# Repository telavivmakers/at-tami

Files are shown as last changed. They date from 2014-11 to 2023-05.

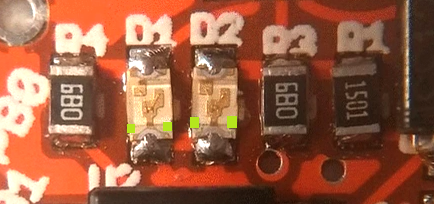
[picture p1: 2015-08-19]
assembly/led_attami.png

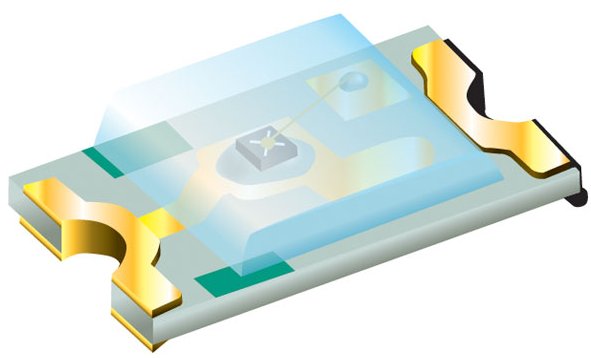
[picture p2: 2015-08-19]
assembly/0805led.jpg

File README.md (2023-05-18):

ATtami עָלֵקדוּאִינו
=================

fork of littlewire AVR based Vusb dev board and various other efforts around the ATtiny85 <br>
more at [docs.telavivmakers.space/attami](https://docs.telavivmakers.space/attami)<br>

Schematics
===

[ATtami board schema](https://github.com/telavivmakers/at-tami/raw/master/ATTAMI-V0.00.sch.pdf)

board layout
===

ATtami board (ver 2.1) backside
ATtami board (ver 2.1)

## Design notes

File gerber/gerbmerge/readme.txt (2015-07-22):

== ATtami-ver-17 8/19/2014 ==
gerber files for 4x4 panel (10x10cm)

panel processed using gerbv[1] python script
from CAM job made via eagle PCB[2]
includes .gvp file which is a gerber viewer[3]

contact yair99@gmail.com

[1] http://174.136.57.11/~ruggedci/gerbmerge/
[2] http://www.cadsoftusa.com/
[3] http://gerbv.sourceforge.net/

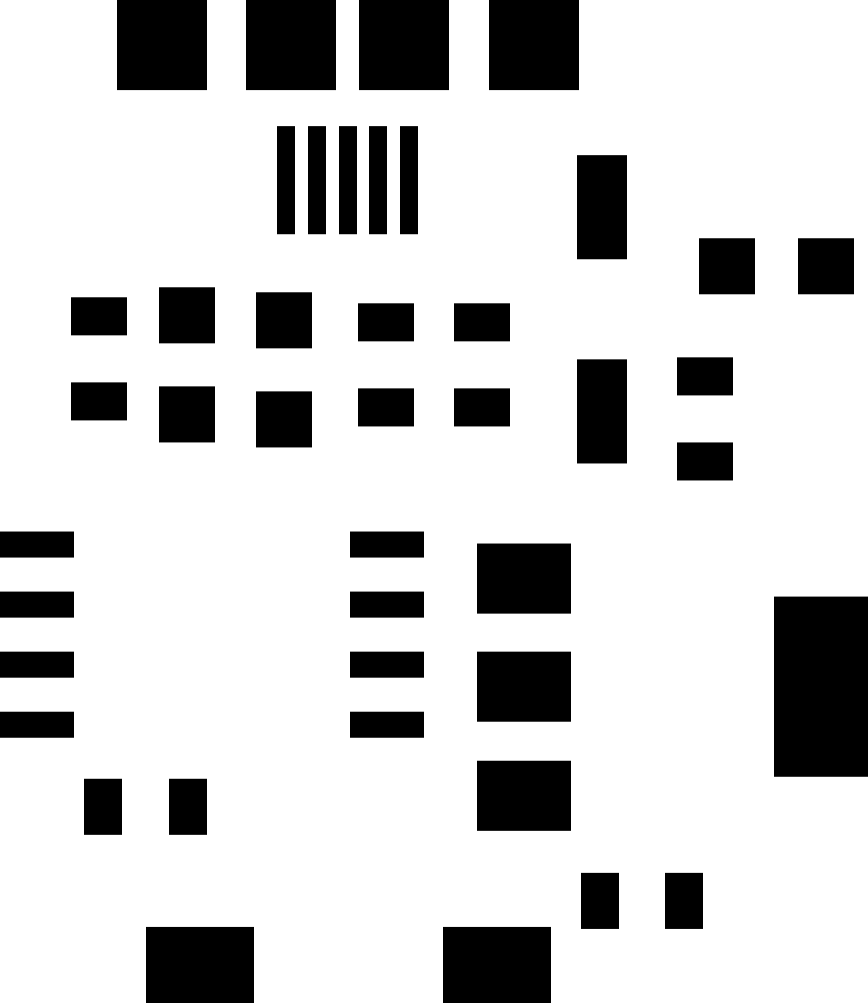
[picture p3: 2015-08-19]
plotter/ATtami-V00-stencil-elragex4.png

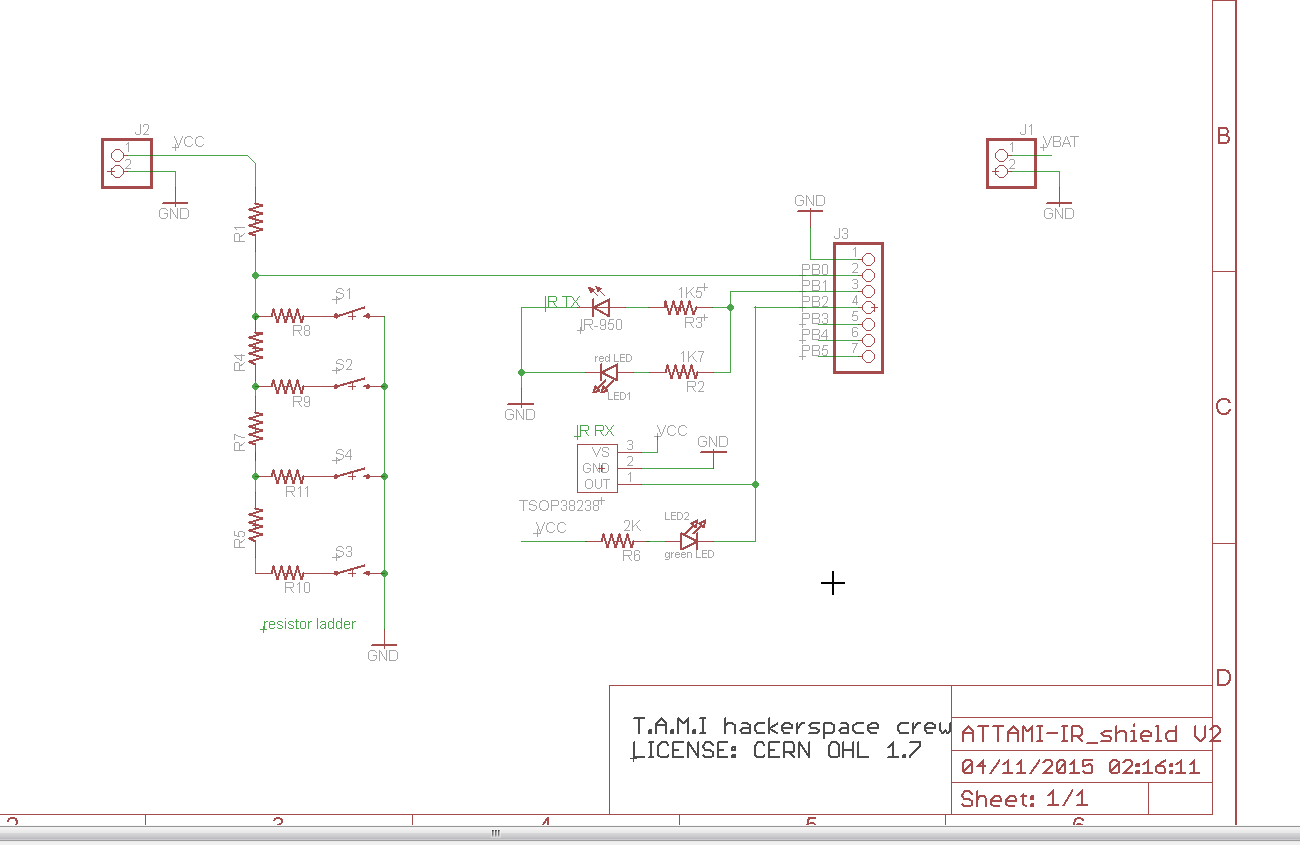
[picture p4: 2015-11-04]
shields/ir-shield/ir-sheild.png

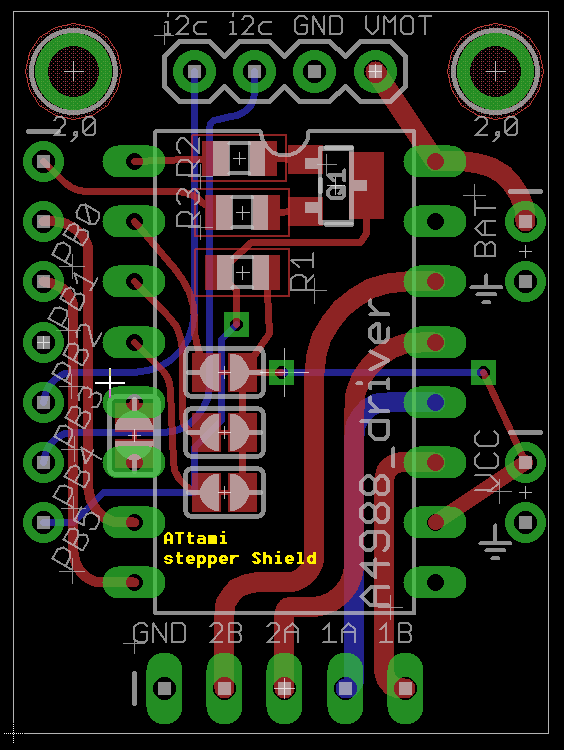
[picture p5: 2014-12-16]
shields/stepperDriver/ATTAMI-Shield-stepperDriver.brd.png

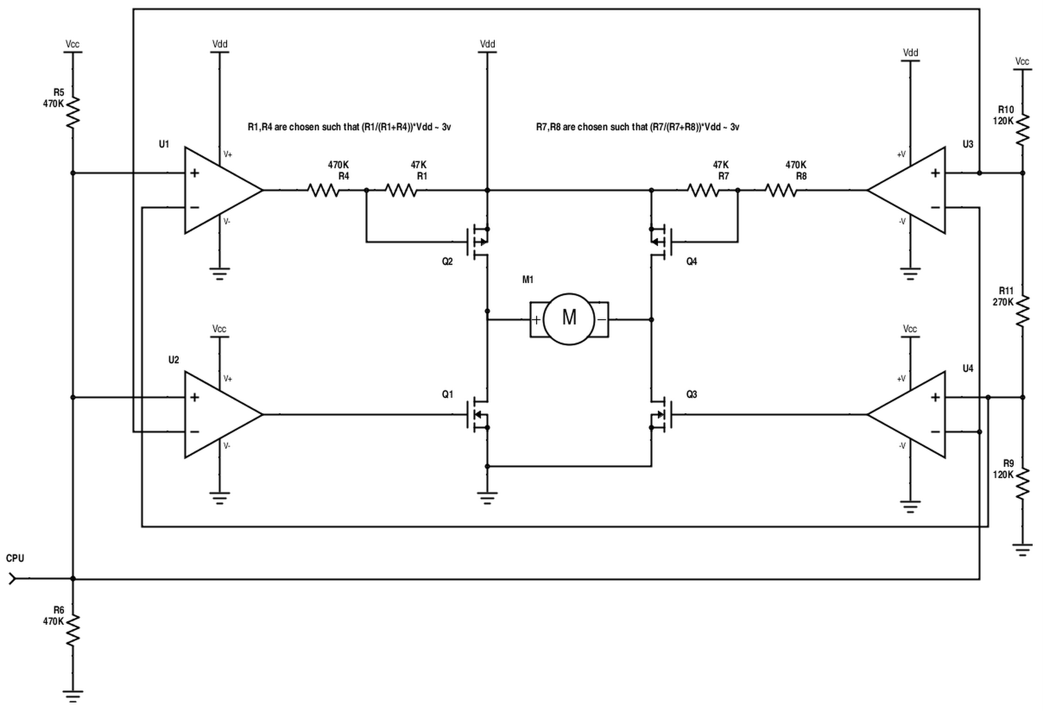
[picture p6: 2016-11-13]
shields/diyStepperDriver/udi_hbridge_w_opamps.png

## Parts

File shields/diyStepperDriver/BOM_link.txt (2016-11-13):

https://docs.google.com/spreadsheets/d/1dIvlz9Zhw2C25BC9nijCdQvVHDtH89HcU7y3oBZd_WM/edit#gid=0

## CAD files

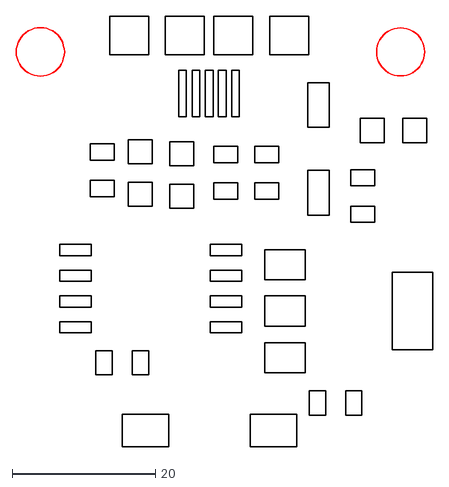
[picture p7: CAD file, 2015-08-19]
plotter/ATtami-V00-stencil.dxf
58.1 x 60.1

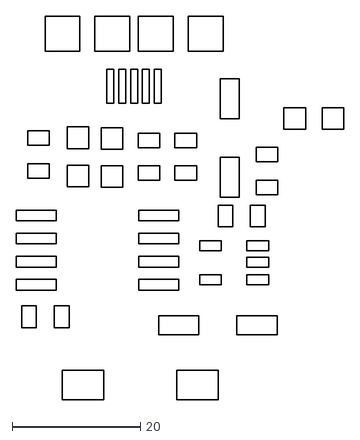
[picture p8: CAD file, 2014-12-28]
plotter/drawing.dxf.DesktopCuttingPlotter.dxf
51.0 x 59.7

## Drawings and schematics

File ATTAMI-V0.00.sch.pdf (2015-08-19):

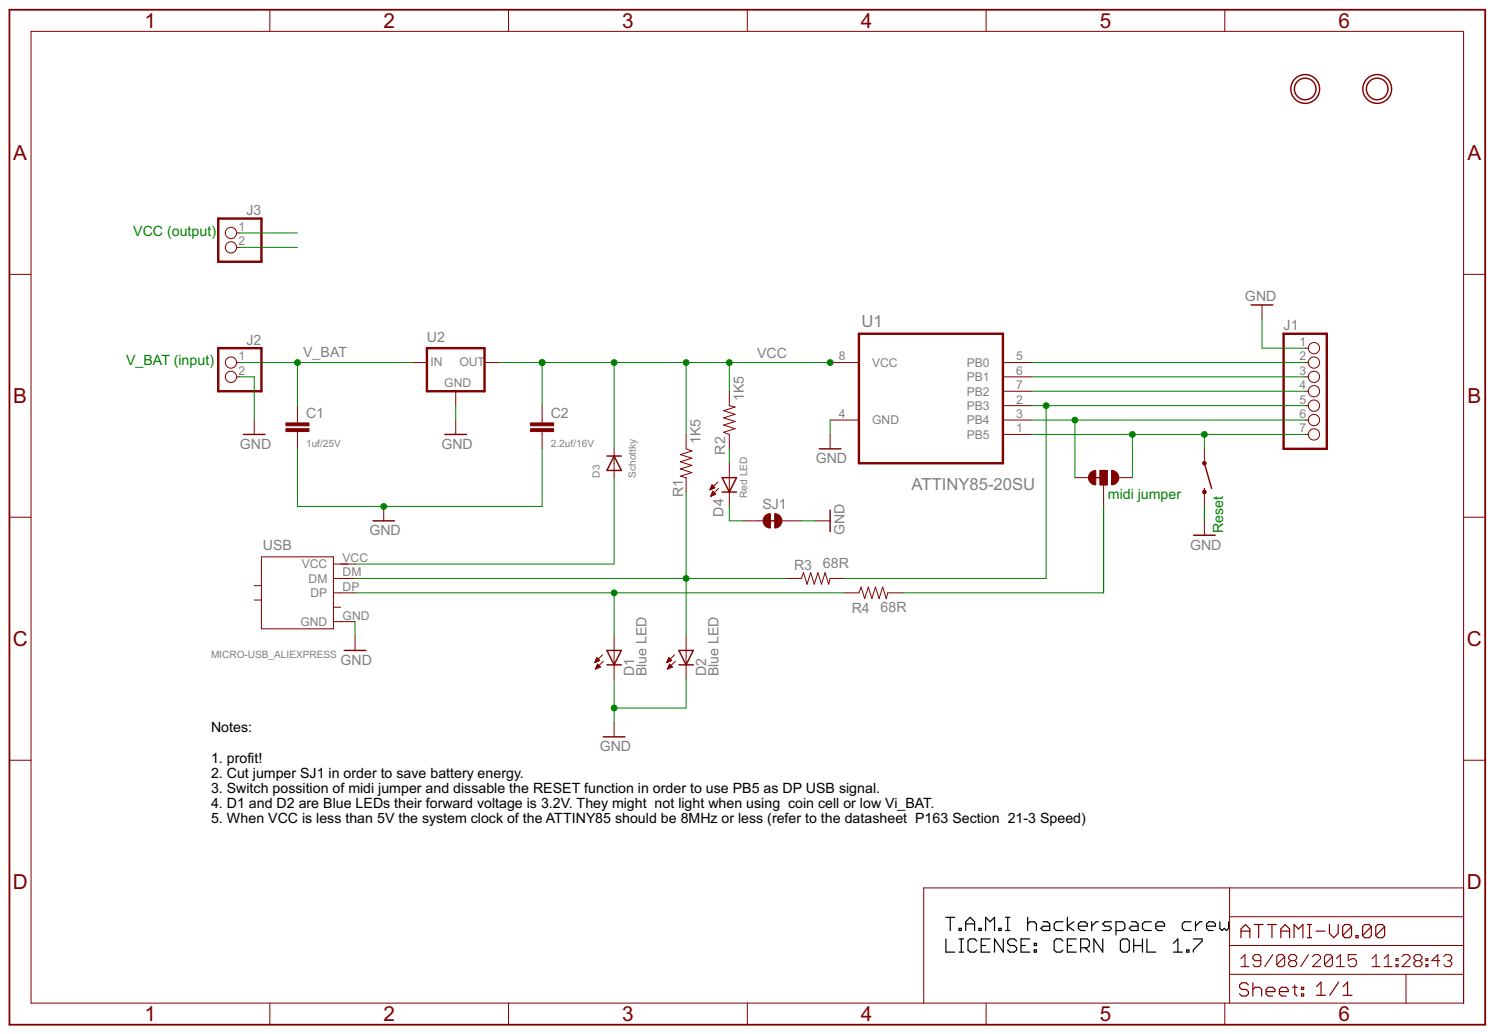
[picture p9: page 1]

2. Cut jumper SJ1 in order to save battery energy. 3. Switch possition of midi jumper and dissable the RESET function in order to use PB5 as DP USB signal. 4. D1 and D2 are Blue LEDs their forward voltage is 3.2V. They might not light when using coin cell or low Vi_BAT. 5. When VCC is less than 5V the system clock of the ATTINY85 should be 8MHz or less (refer to the datasheet P163 Section 21-3 Speed)

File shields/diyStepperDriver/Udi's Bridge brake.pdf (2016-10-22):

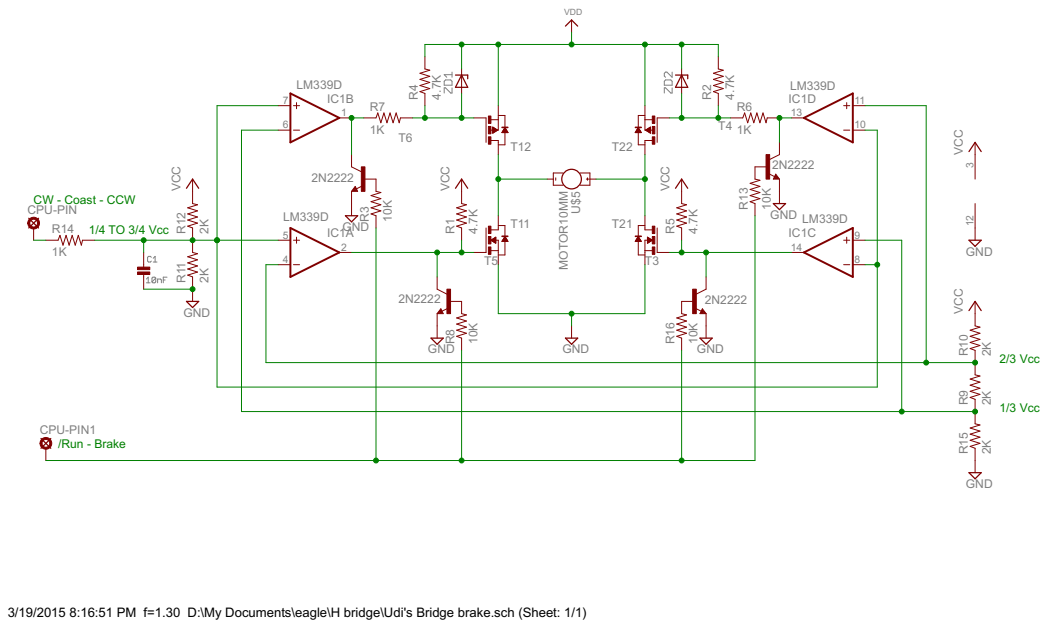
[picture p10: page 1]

3/19/2015 8:16:51 PM f=1.30 D:\My Documents\eagle\H bridge\Udi's Bridge brake.sch (Sheet: 1/1)

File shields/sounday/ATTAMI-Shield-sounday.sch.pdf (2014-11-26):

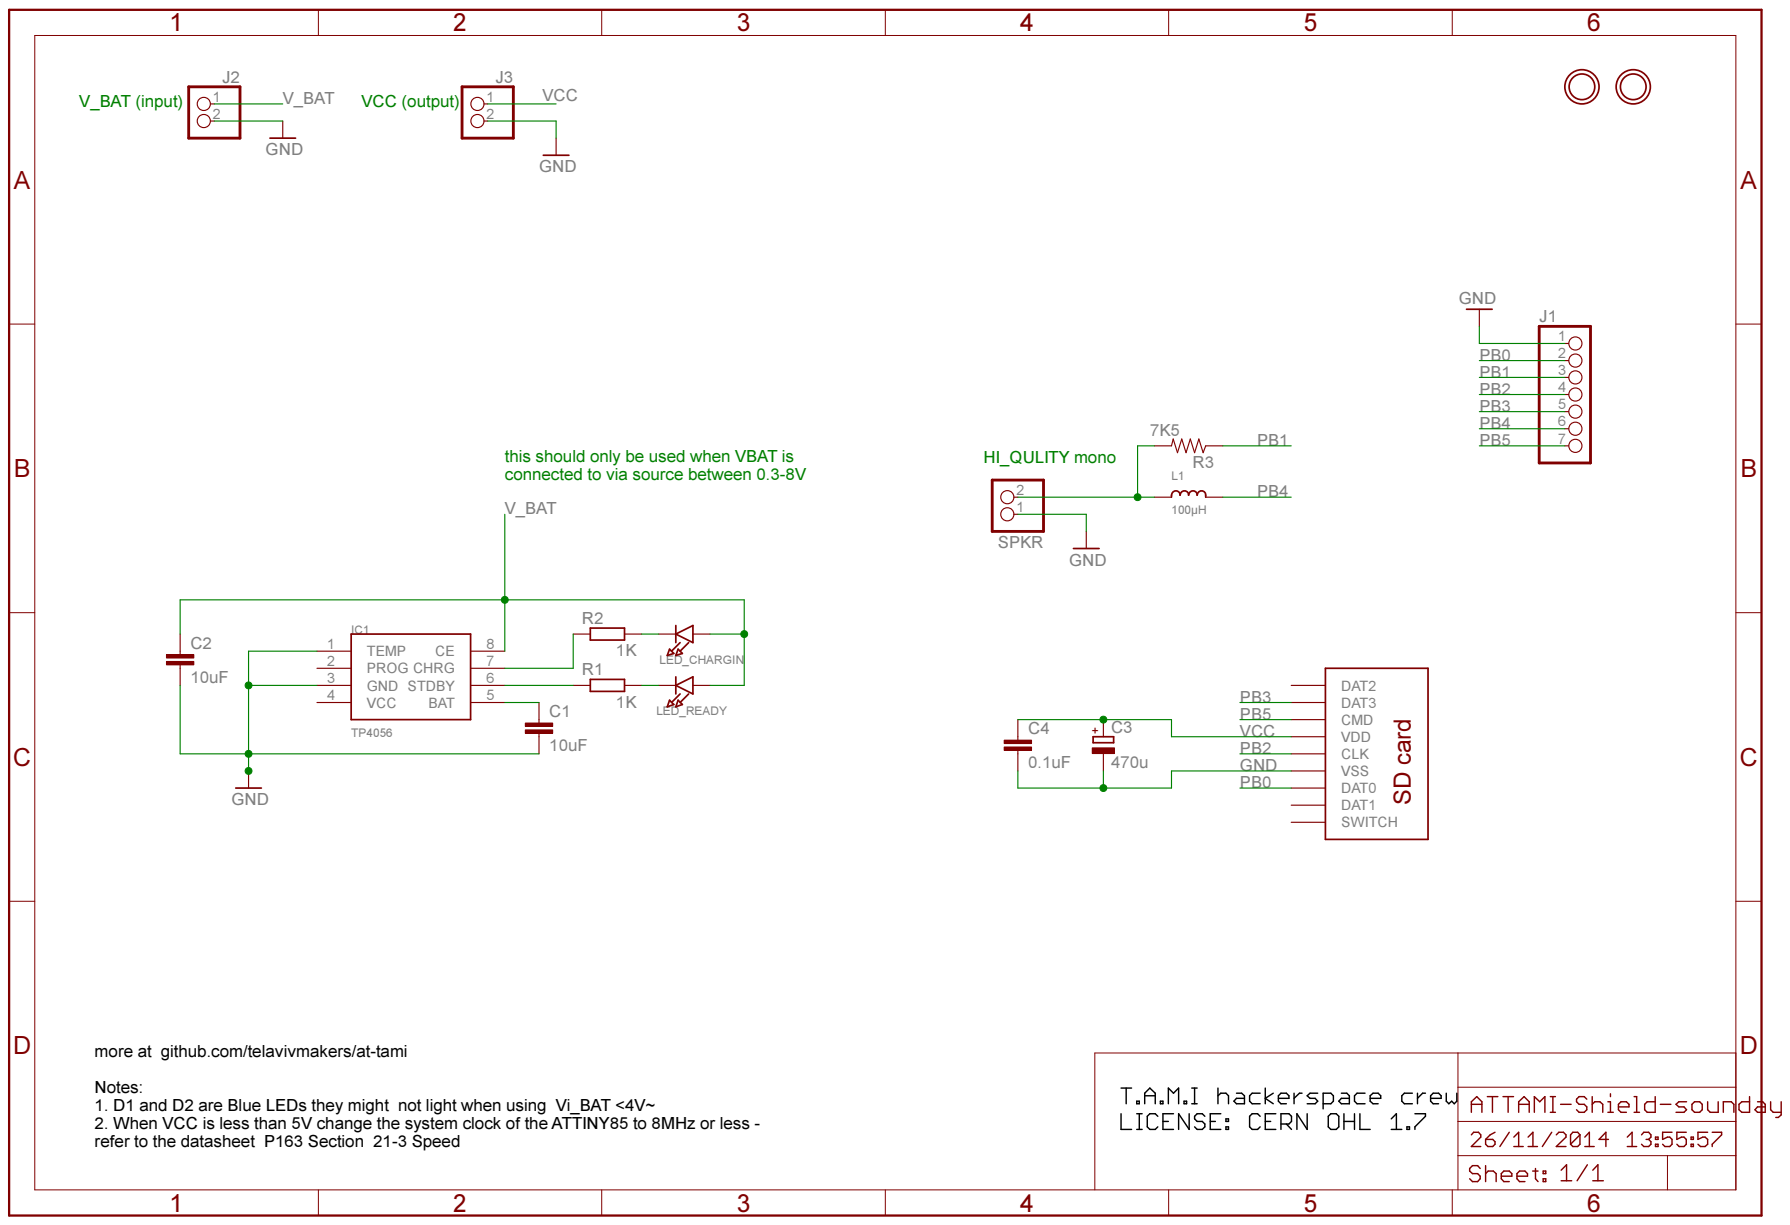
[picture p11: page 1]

this should only be used when VBAT is
connected to via source between 0.3-8V

more at github.com/telavivmakers/at-tami

Notes:
1. D1 and D2 are Blue LEDs they might not light when using Vi_BAT <4V~
2. When VCC is less than 5V change the system clock of the ATTINY85 to 8MHz or less -
refer to the datasheet P163 Section 21-3 Speed

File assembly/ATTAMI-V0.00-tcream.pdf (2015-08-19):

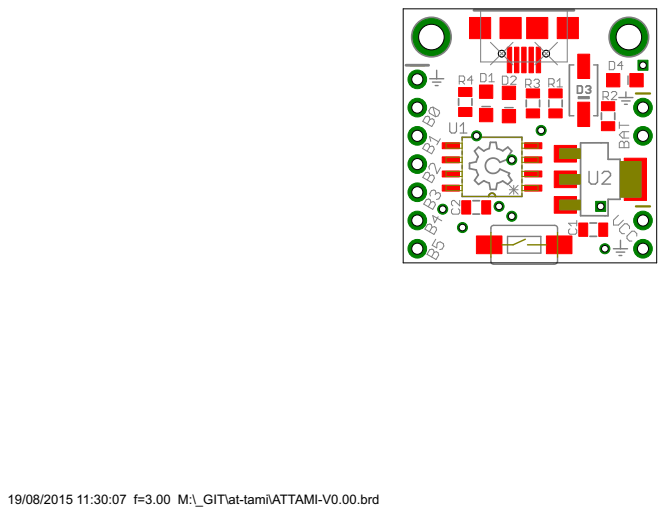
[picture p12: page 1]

19/08/2015 11:30:07 f=3.00 M:\_GIT\at-tami\ATTAMI-V0.00.brd

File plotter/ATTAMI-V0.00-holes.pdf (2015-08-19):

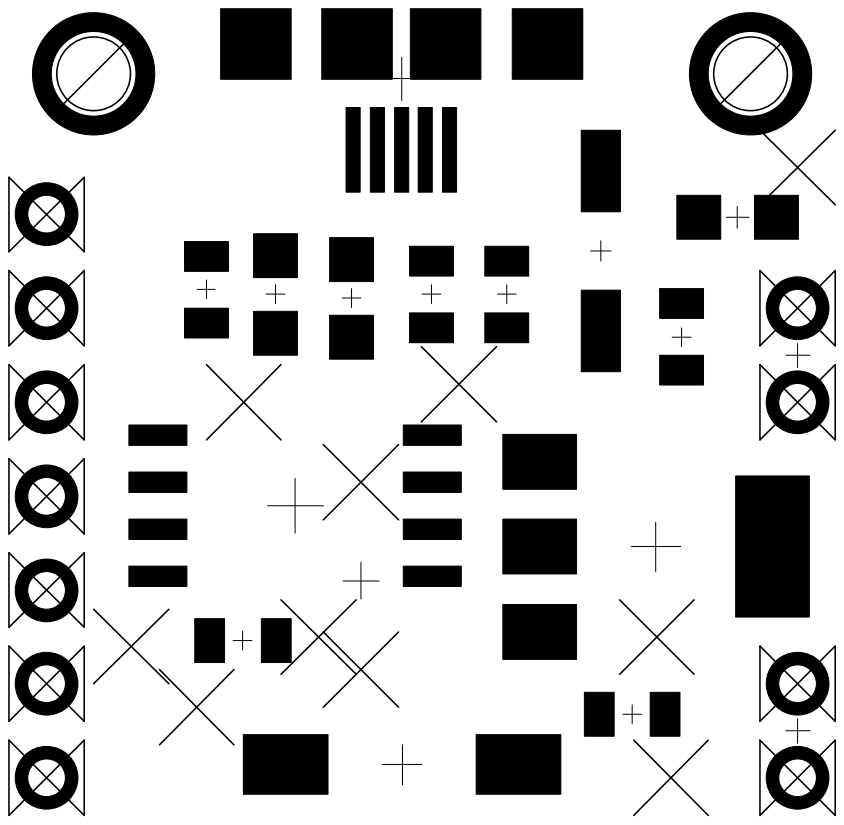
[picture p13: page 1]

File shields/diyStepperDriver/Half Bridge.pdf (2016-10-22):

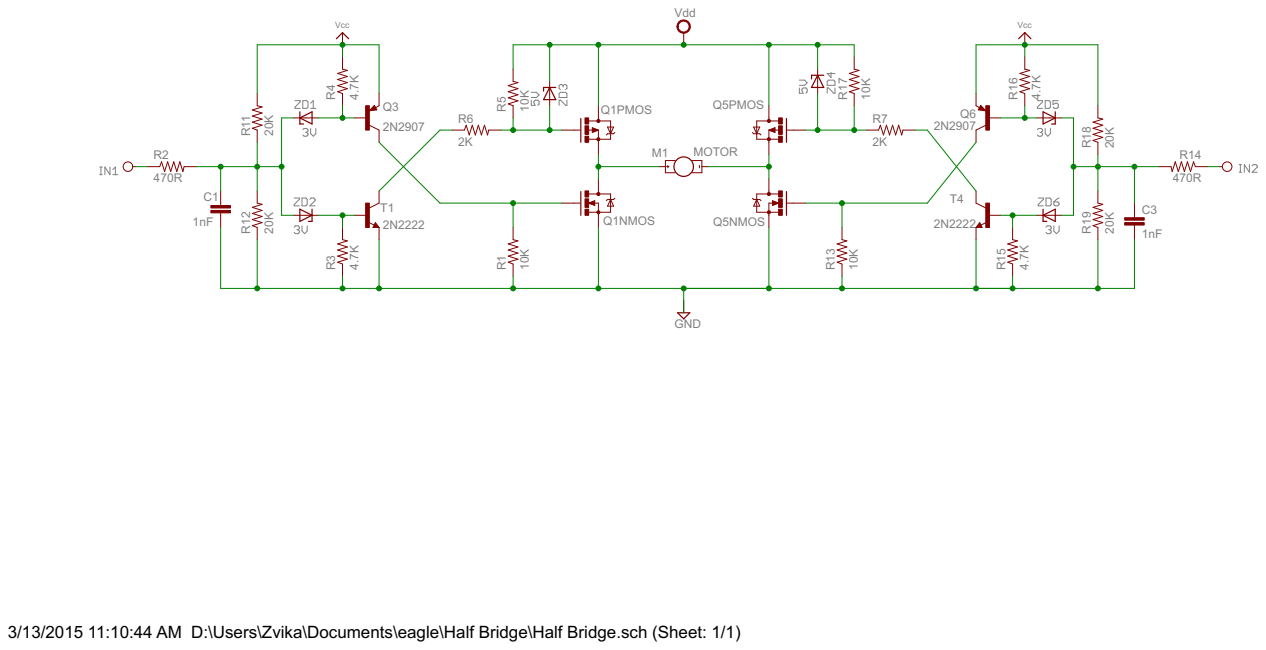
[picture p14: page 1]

3/13/2015 11:10:44 AM D:\Users\Zvika\Documents\eagle\Half Bridge\Half Bridge.sch (Sheet: 1/1)

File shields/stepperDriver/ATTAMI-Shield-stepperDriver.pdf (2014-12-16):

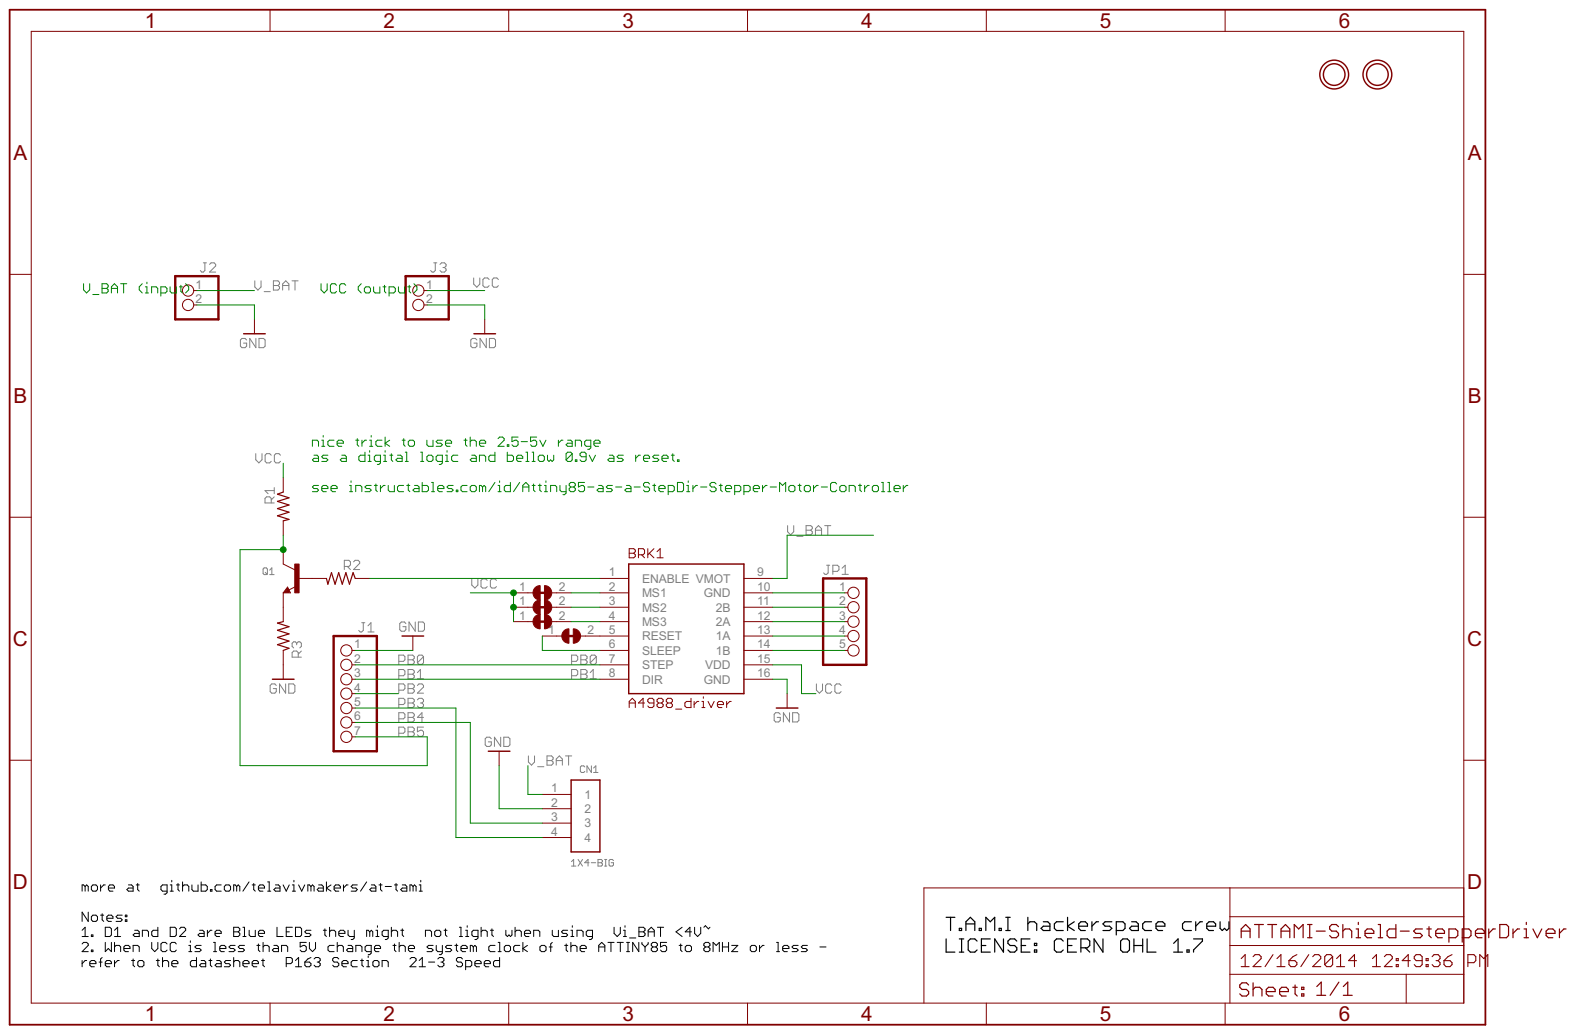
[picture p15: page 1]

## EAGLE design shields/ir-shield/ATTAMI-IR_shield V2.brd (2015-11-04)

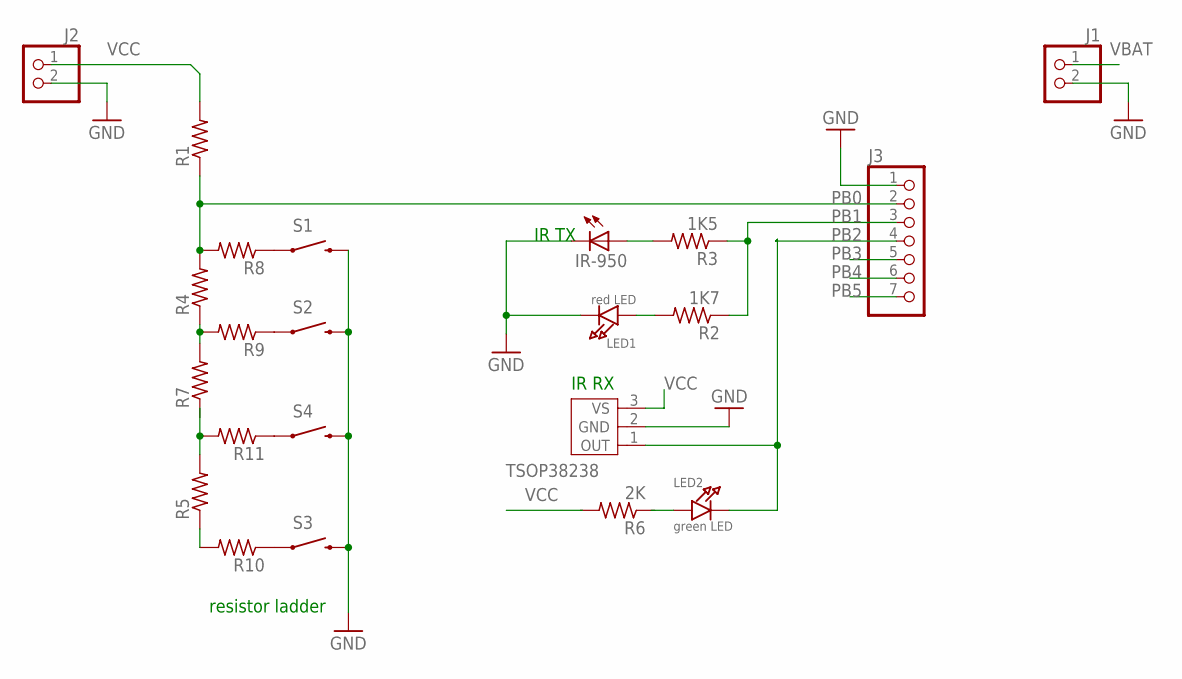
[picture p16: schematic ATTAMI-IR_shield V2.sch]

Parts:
IR-950: LEDIRL80A; IRL80A
J1, J2: HEADER-1X2ROUND; 1X02_ROUND
J3: HEADER-1X7ROUND; 1X07_ROUND
LED1: red LED; CHIPLED_0805
LED2: green LED; CHIPLED_0805
R1, R4, R5, R7, R8, R9, R10, R11: R-US_M0805; M0805
R2: 1K7; M0805
R3: 1K5; M0805
R6: 2K; M0805
S1, S2, S3, S4: SWITCH-MOMENTARY-2-SMD-1101NE; TACTILE-SWITCH-1101NE
TSOP38238: TSOP382; 3P-2.54-4.8X5X6.95H

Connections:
GND: IR-950.K (C), J1.2, J2.2, J3.1, LED1.C, S1.P$2 (2), S2.P$2 (2), S3.P$2 (2), S4.P$2 (2), TSOP38238.2 (GND)
unnamed: R9.1, S2.P$1 (1)
unnamed: R8.1, S1.P$1 (1)
unnamed: R10.1, S3.P$1 (1)
unnamed: LED1.A, R2.2
unnamed: R5.2, R11.2
unnamed: R4.1, R7.2, R9.2
unnamed: R5.1, R10.2
unnamed: IR-950.A, R3.2
unnamed: R11.1, S4.P$1 (1)
PB0: J3.2, R1.1, R4.2, R8.2
PB1: J3.3, R2.1, R3.1
PB2: J3.4, LED2.C, TSOP38238.1 (OUT)
PB3: J3.5
PB4: J3.6
PB5: J3.7
VBAT: J1.1
VCC: J2.1, R1.2, TSOP38238.3 (VS)

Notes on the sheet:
resistor ladder
IR TX
IR RX

Board: 2 copper layers, 22 parts (0 on the bottom side), 14 nets, no tracks yet.

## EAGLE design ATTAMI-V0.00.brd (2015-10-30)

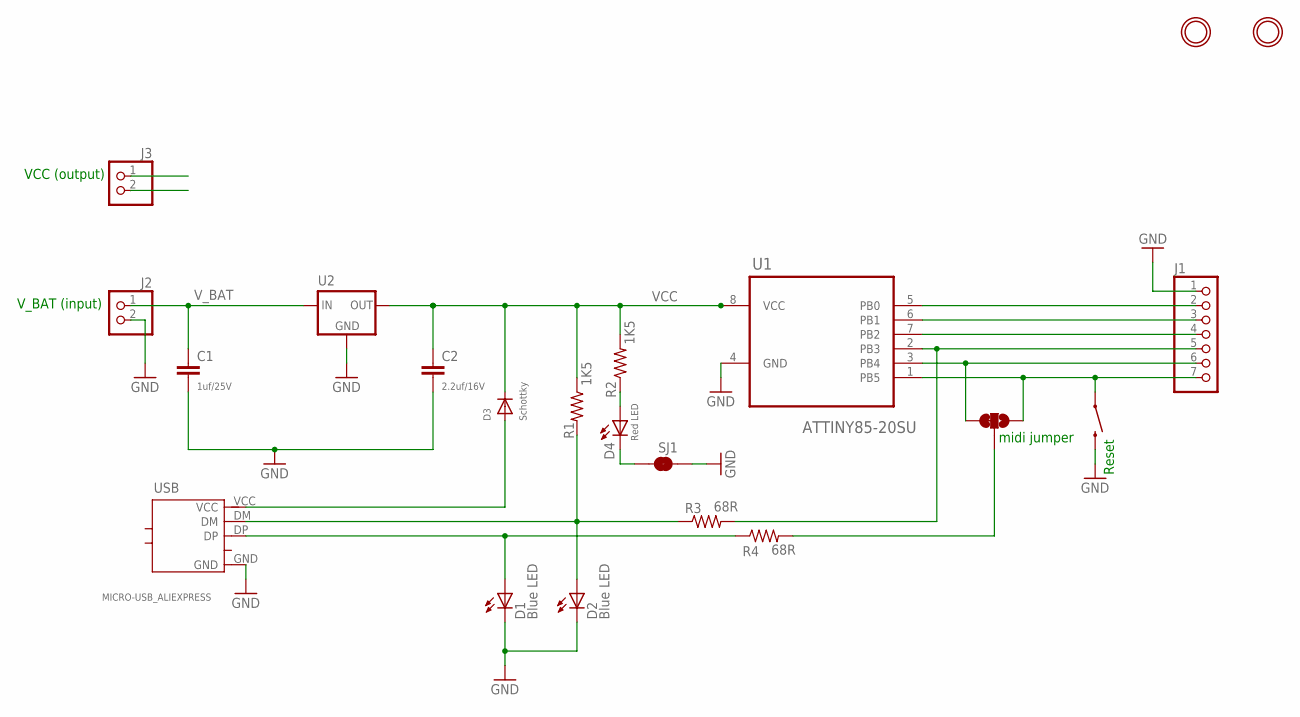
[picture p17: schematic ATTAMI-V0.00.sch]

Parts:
C1: 1uf/25V; 0805
C2: 2.2uf/16V; 0805
D1, D2: Blue LED; LED-805
D3: Schottky; SOD-323
D4: Red LED; LED-805
J1: HEADER-1X7ROUND; 1X07_ROUND
J2, J3: HEADER-1X2ROUND; 1X02_ROUND
MIDI: JUMPER-PAD-3-2OF3_NC_BY_TRACE_SMALL; PAD-JUMPER-3-2OF3_NC_BY_TRACE_YES_SILK_FULL_BOX
R1, R2: 1K5; 0805
R3, R4: 68R; 0805
S1: SWITCH-MOMENTARY-2-SMD-1101NE; TACTILE-SWITCH-1101NE
SJ1: JUMPER-PAD-2-NC_BY_TRACE; PAD-JUMPER-2-NC_BY_TRACE_YES_SILK
U1: ATTINY85-20SU; SOIC127P798X216-8N
U2: XXX1117SOT-232; SOT-223
U$1, U$2: MOUNTINGHOLE2.0; MOUNTINGHOLE_2.0_PLATED
USB: MICRO-USB_ALIEXPRESS; USB-MICRO-ALIEXPRESS

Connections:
GND: C1.2, C2.2, D1.C, D2.C, J1.1, J2.2, J3.2, S1.P$2 (2), SJ1.1, U1.4 (GND), U2.1 (GND), USB.GND
unnamed: MIDI.2, R4.2
unnamed: D1.A, R4.1, USB.DP
unnamed: D2.A, R1.2, R3.1, USB.DM
unnamed: D4.A, R2.1
unnamed: D4.C, SJ1.2
PB0: J1.2, U1.5 (PB0)
PB1: J1.3, U1.6 (PB1)
PB2: J1.4, U1.7 (PB2)
PB3: J1.5, R3.2, U1.2 (PB3)
PB4: J1.6, MIDI.3, U1.3 (PB4)
PB5: J1.7, MIDI.1, S1.P$1 (1), U1.1 (PB5)
V-BUS: D3.AQ (A), USB.VCC
VCC: C2.1, D3.CQ (C), J3.1, R1.1, R2.2, U1.8 (VCC), U2.2 (OUT), U2.4 (OUT)
V_BAT: C1.1, J2.1, U2.3 (IN)

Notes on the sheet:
VCC (output)
V_BAT (input)
Reset
midi jumper

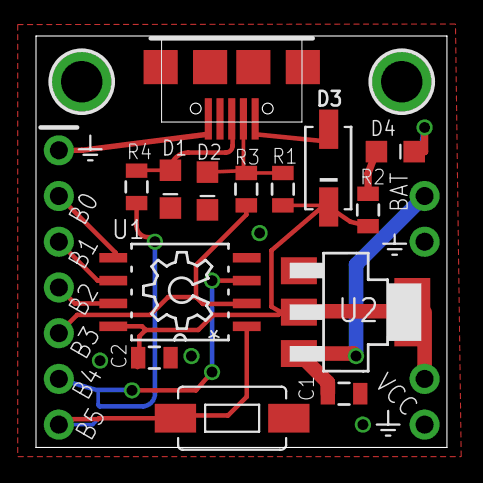
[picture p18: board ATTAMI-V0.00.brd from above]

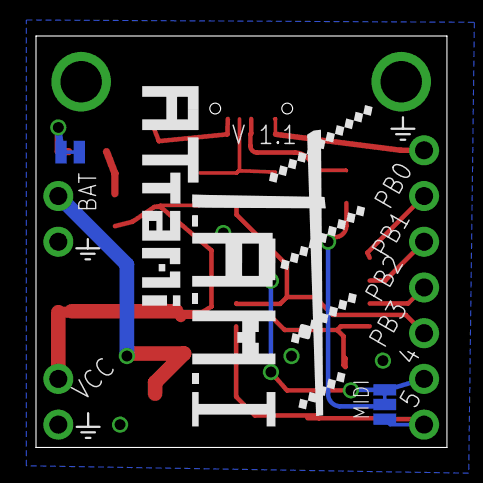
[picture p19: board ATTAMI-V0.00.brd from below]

Board: 2 copper layers, 22.8 x 22.9 mm, 22 parts (2 on the bottom side), 15 nets.

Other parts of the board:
U$3: OSHW_6X150_NOTEXT

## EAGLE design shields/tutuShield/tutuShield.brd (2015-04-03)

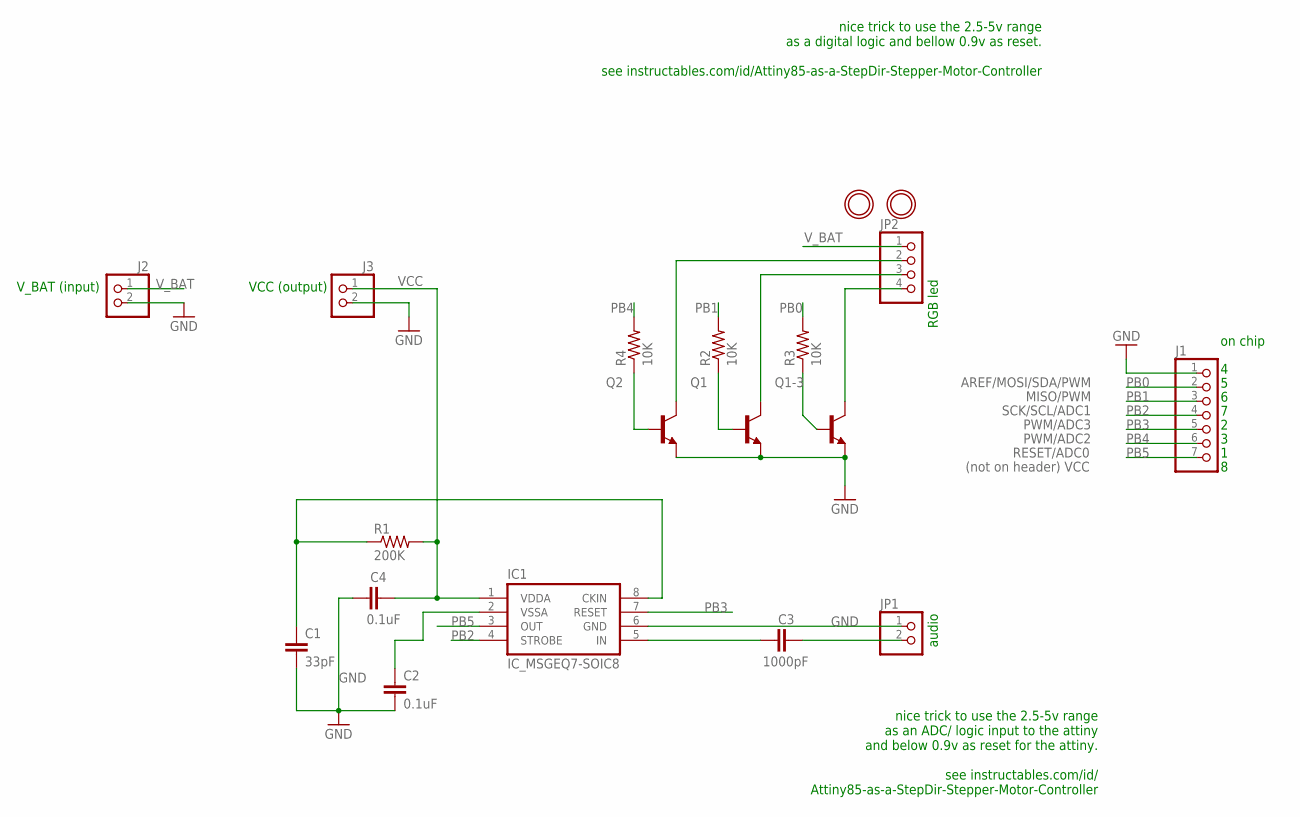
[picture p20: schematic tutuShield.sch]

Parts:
C1: 33pF; 0805
C2, C4: 0.1uF; 0805
C3: 1000pF; 0805
IC1: IC_MSGEQ7-SOIC8; SOIC-8
J1: HEADER-1X7ROUND; 1X07_ROUND
J2, J3: HEADER-1X2ROUND; 1X02_ROUND
JP1: HEADER-1X2ROUND; 1X02_ROUND
JP2: HEADER-1X4ROUND; 1X04_ROUND
Q1, Q1-3, Q2: TRANSISTOR_BJT_NPN-SOT-23-BEC; SOT-23
R1: 200K; 0805
R2, R3, R4: 10K; 0805
U$1, U$2: MOUNTINGHOLE2.0; MOUNTINGHOLE_2.0_PLATED

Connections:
CKIN: C1.1, IC1.8 (CKIN), R1.1
GND: C1.2, C2.2, C4.1, IC1.6 (GND), J1.1, J2.2, J3.2, JP1.1, Q1.2 (E), Q1-3.2 (E), Q2.2 (E)
IN: C3.1, IC1.5 (IN)
unnamed: C3.2, JP1.2
unnamed: Q1-3.1 (B), R3.1
unnamed: JP2.2, Q2.3 (C)
unnamed: C2.1, IC1.2 (VSSA)
unnamed: Q1.1 (B), R2.1
unnamed: Q2.1 (B), R4.1
unnamed: JP2.4, Q1-3.3 (C)
unnamed: JP2.3, Q1.3 (C)
PB0: J1.2, R3.2
PB1: J1.3, R2.2
PB2: IC1.4 (STROBE), J1.4
PB3: IC1.7 (RESET), J1.5
PB4: J1.6, R4.2
PB5: IC1.3 (OUT), J1.7
VCC: C4.2, IC1.1 (VDDA), J3.1, R1.2
V_BAT: J2.1, JP2.1

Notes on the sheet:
VCC (output)
V_BAT (input)
RESET/ADC0
PWM/ADC3
SCK/SCL/ADC1
PWM/ADC2
MISO/PWM
AREF/MOSI/SDA/PWM
on chip 4 5 6 7 2 3 1 8
(not on header) VCC
nice trick to use the 2.5-5v range as a digital logic and bellow 0.9v as reset. see instructables.com/id/Attiny85-as-a-StepDir-Stepper-Motor-Controller
nice trick to use the 2.5-5v range as an ADC/ logic input to the attiny and below 0.9v as reset for the attiny. see instructables.com/id/ Attiny85-as-a-StepDir-Stepper-Motor-Controller
audio
RGB led

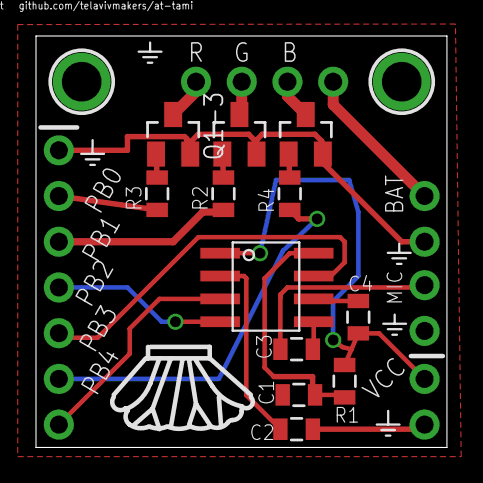
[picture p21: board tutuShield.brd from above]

Board: 2 copper layers, 22.8 x 22.9 mm, 19 parts (0 on the bottom side), 19 nets.

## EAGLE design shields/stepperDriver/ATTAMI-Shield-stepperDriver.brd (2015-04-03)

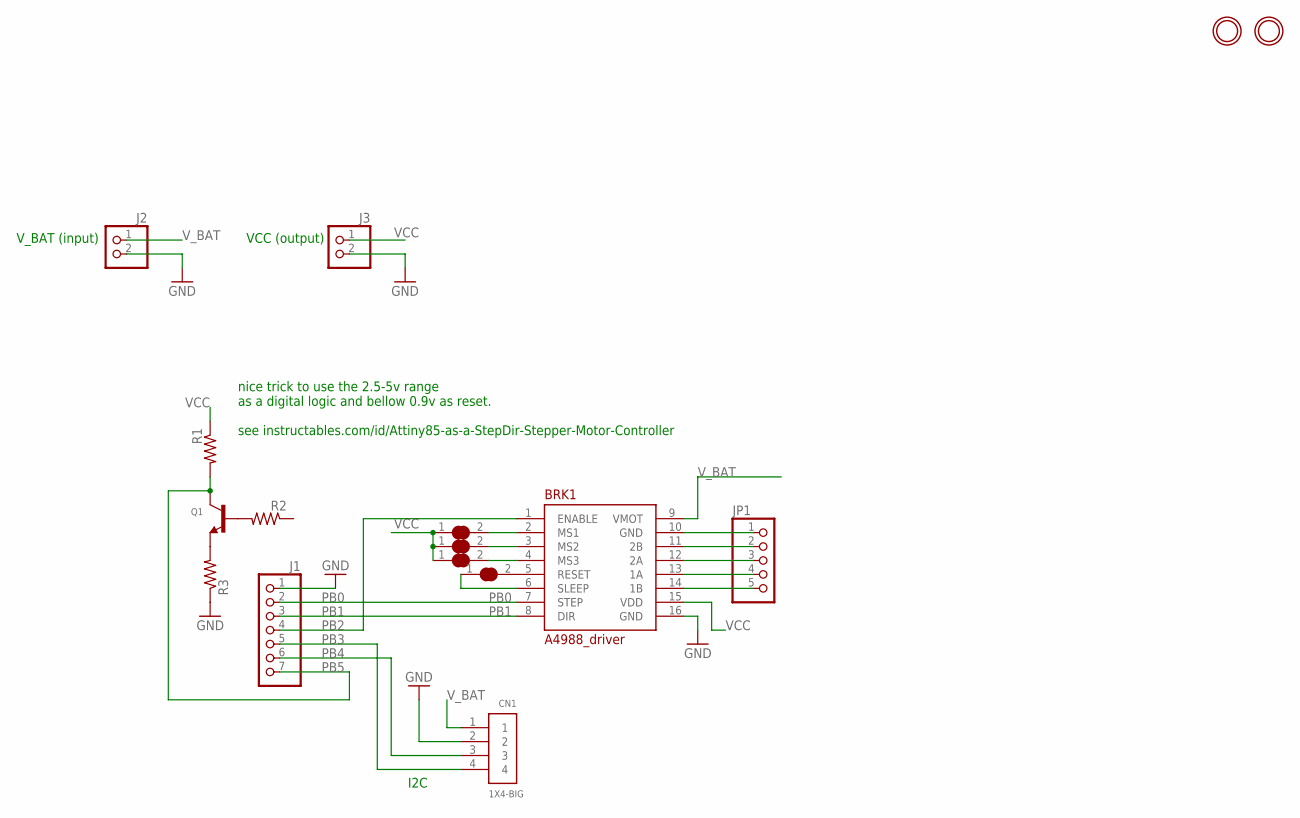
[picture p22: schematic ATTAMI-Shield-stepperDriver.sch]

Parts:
BRK1: A4988_driver; DIL16
CN1: 1X4-BIG; 1X04-BIG
J1: HEADER-1X7ROUND; 1X07_ROUND
J2, J3: HEADER-1X2ROUND; 1X02_ROUND
JP1: HEADER-1X5; 1X05_OVAL
Q1: TRANSISTOR_NPNWAVE; SOT23-W
R1, R2, R3: R-US_R0805; R0805
SJ1, SJ2, SJ3, SJ4: SOLDERJUMPER_CLOSED; SOLDERJUMPER_CLOSEDWIRE
U$1, U$2: MOUNTINGHOLE2.0; MOUNTINGHOLE_2.0_PLATED

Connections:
GND: BRK1.10 (GND), BRK1.16 (GND), CN1.2, J1.1, J2.2, J3.2, JP1.1, R3.1
unnamed: BRK1.5 (RESET), SJ4.2
unnamed: BRK1.11 (2B), JP1.2
unnamed: Q1.2 (E), R3.2
unnamed: Q1.1 (B), R2.2
unnamed: BRK1.12 (2A), JP1.3
unnamed: BRK1.13 (1A), JP1.4
unnamed: BRK1.14 (1B), JP1.5
unnamed: BRK1.6 (SLEEP), SJ4.1
unnamed: BRK1.2 (MS1), SJ3.2
unnamed: BRK1.3 (MS2), SJ2.2
unnamed: BRK1.4 (MS3), SJ1.2
PB0: BRK1.7 (STEP), J1.2
PB1: BRK1.8 (DIR), J1.3
PB2: BRK1.1 (ENABLE), J1.4
PB3: CN1.4, J1.5
PB4: CN1.3, J1.6
PB5: J1.7, Q1.3 (C), R1.2
VCC: BRK1.15 (VDD), J3.1, R1.1, SJ1.1, SJ2.1, SJ3.1
V_BAT: BRK1.9 (VMOT), CN1.1, J2.1

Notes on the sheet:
VCC (output)
V_BAT (input)
nice trick to use the 2.5-5v range as a digital logic and bellow 0.9v as reset. see instructables.com/id/Attiny85-as-a-StepDir-Stepper-Motor-Controller
I2C

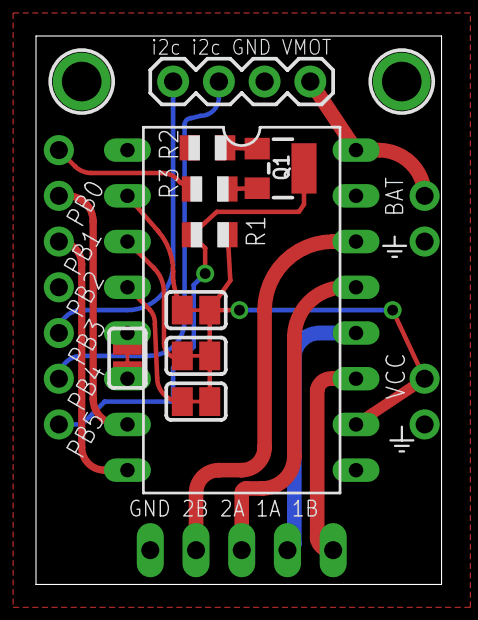
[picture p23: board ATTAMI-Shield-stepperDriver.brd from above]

Board: 2 copper layers, 22.5 x 30.5 mm, 16 parts (0 on the bottom side), 20 nets.

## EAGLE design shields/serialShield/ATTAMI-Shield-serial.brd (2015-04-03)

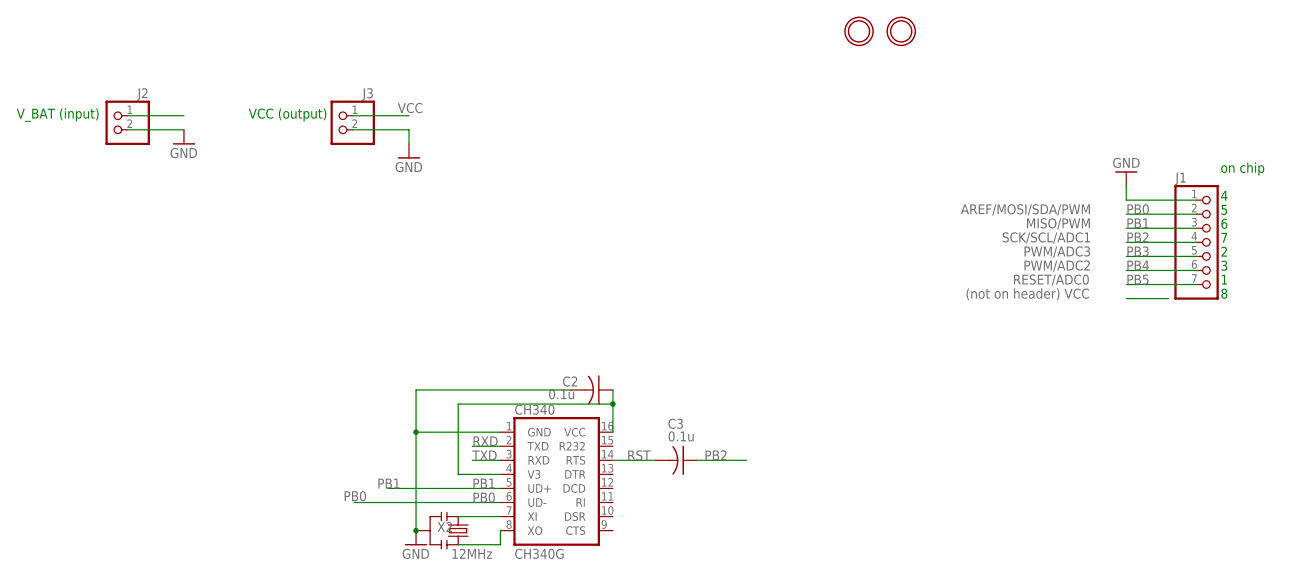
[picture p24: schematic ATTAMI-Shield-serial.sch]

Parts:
C2, C3: 0.1u; C0603
CH340: CH340G; SO16
J1: HEADER-1X7ROUND; 1X07_ROUND
J2, J3: HEADER-1X2ROUND; 1X02_ROUND
U$1, U$2: MOUNTINGHOLE2.0; MOUNTINGHOLE_2.0_PLATED
X2: 12MHz; RESONATOR-SMD

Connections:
GND: C2.2, CH340.1 (GND), J1.1, J2.2, J3.2, X2.2
unnamed: CH340.7 (XI), X2.1
unnamed: CH340.8 (XO), X2.3
PB0: CH340.6 (UD-), J1.2
PB1: CH340.5 (UD+), J1.3
PB2: C3.1, J1.4
PB3: J1.5
PB4: J1.6
PB5: J1.7
RST: C3.2, CH340.14 (RTS)
RXD: CH340.2 (TXD)
TXD: CH340.3 (RXD)
VCC: C2.1, CH340.4 (V3), CH340.16 (VCC), J3.1

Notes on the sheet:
VCC (output)
V_BAT (input)
RESET/ADC0
PWM/ADC3
SCK/SCL/ADC1
PWM/ADC2
MISO/PWM
AREF/MOSI/SDA/PWM
on chip 4 5 6 7 2 3 1 8
(not on header) VCC

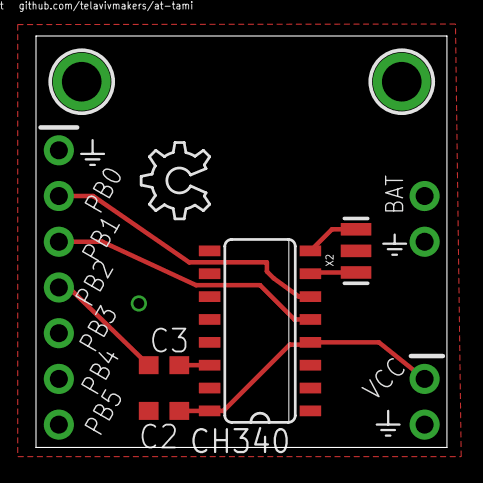
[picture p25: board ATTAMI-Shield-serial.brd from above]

Board: 2 copper layers, 22.8 x 22.9 mm, 10 parts (0 on the bottom side), 8 nets.

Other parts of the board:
U$3: OSHW_6X150_NOTEXT

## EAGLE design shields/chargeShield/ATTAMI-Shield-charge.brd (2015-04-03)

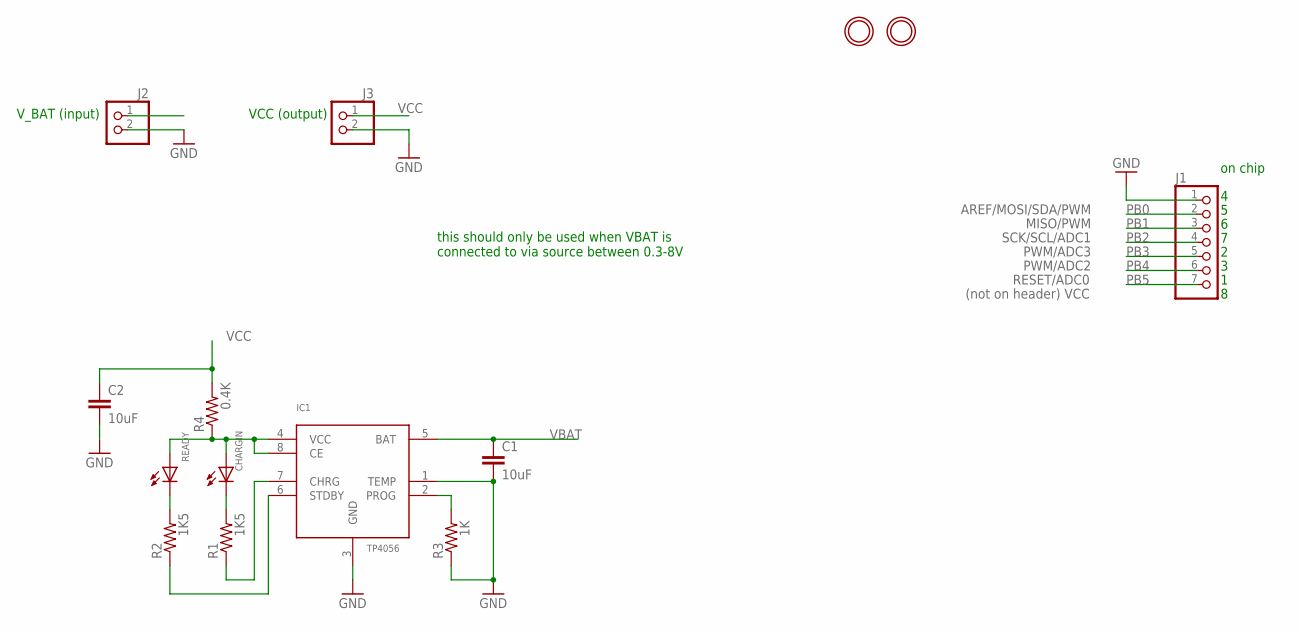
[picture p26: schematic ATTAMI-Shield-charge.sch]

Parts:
C1, C2: 10uF; 0805
CHARGIN: LED-0805; LED-805
IC1: TP4056; SOP-8
J1: HEADER-1X7ROUND; 1X07_ROUND
J2, J3: HEADER-1X2ROUND; 1X02_ROUND
R1, R2: 1K5; 0805
R3: 1K; 0805
R4: 0.4K; 0805
READY: LED-0805; LED-805
U$1, U$2: MOUNTINGHOLE2.0; MOUNTINGHOLE_2.0_PLATED

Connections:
$02: CHARGIN.A, IC1.4 (VCC), IC1.8 (CE), R4.1, READY.A
GND: C1.2, C2.2, IC1.1 (TEMP), IC1.3 (GND), J1.1, J2.2, J3.2, R3.1
unnamed: IC1.2 (PROG), R3.2
unnamed: R2.2, READY.C
unnamed: CHARGIN.C, R1.2
unnamed: IC1.6 (STDBY), R2.1
unnamed: IC1.7 (CHRG), R1.1
PB0: J1.2
PB1: J1.3
PB2: J1.4
PB3: J1.5
PB4: J1.6
PB5: J1.7
VBAT: C1.1, IC1.5 (BAT), J2.1
VCC: C2.1, J3.1, R4.2

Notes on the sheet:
VCC (output)
V_BAT (input)
RESET/ADC0
PWM/ADC3
SCK/SCL/ADC1
PWM/ADC2
MISO/PWM
AREF/MOSI/SDA/PWM
on chip 4 5 6 7 2 3 1 8
(not on header) VCC
this should only be used when VBAT is connected to via source between 0.3-8V

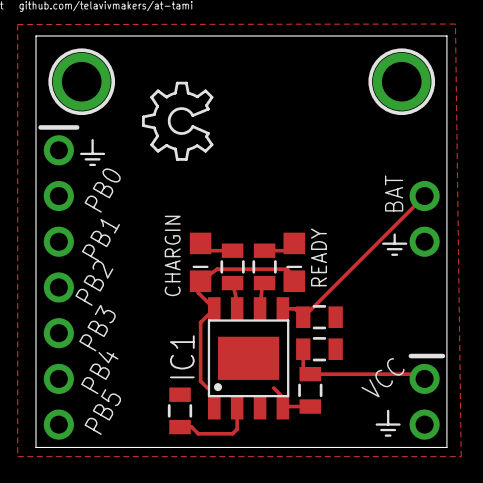
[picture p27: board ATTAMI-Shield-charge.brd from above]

Board: 2 copper layers, 22.8 x 22.9 mm, 15 parts (0 on the bottom side), 9 nets.

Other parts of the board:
U$3: OSHW_6X150_NOTEXT

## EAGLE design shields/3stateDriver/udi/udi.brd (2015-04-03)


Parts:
IC1, IC3: OPAMP-DUALU; SO08
Q1, Q2: IRF7509; MSOP8
R1, R2: RESISTOR-ARRAY0603-ARV; 0603-ARV

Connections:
GND-ISO: Q1.1 (S), Q2.1 (S), R1.4 (1), R2.4 (1)
unnamed: IC1.1 (OUT), R1.1
unnamed: Q1.4 (G), R1.2 (1), R1.8 (2)
unnamed: IC1.3 (+IN), IC1.5 (+IN), R1.3 (1), R1.5 (2)
unnamed: Q1.5 (D), Q1.6 (D), R1.7 (2)
unnamed: Q1.3 (S), Q1.7 (D), Q1.8 (D)
unnamed: IC1.7 (OUT), Q1.2 (G)
unnamed: IC3.1 (OUT), R2.1
unnamed: Q2.4 (G), R2.2 (1), R2.8 (2)
unnamed: IC1.6 (-IN), IC3.5 (+IN)
unnamed: Q2.5 (D), Q2.6 (D), R2.7 (2)
unnamed: Q2.3 (S), Q2.7 (D), Q2.8 (D)
unnamed: IC3.7 (OUT), Q2.2 (G)
V+: IC1.8 (V+), IC3.8 (V+)
V-: IC1.4 (V-), IC3.4 (V-)

Board: 2 copper layers, 6 parts (0 on the bottom side), 15 nets, no tracks yet.

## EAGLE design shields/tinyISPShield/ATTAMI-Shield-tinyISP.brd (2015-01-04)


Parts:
J1: HEADER-1X7ROUND; 1X07_ROUND
J2, J3: HEADER-1X2ROUND; 1X02_ROUND
JP1: HEADER-1X6ROUND; 1X06_ROUND
Q1: TRANSISTOR_NPNSOT23; SOT23
R1: RESISTOR0805-RES; 0805
R2: RESISTORAXIAL-0.3; AXIAL-0.3
T1: 2N2222; TO92-EBC-OVAL
U$1, U$2: MOUNTINGHOLE2.0; MOUNTINGHOLE_2.0_PLATED

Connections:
GND: J1.1, J2.2, J3.2, Q1.2 (E)
PB0: J1.2
PB1: J1.3
PB2: J1.4
PB3: J1.5
PB4: J1.6
PB5: J1.7, Q1.3 (C), R1.1
RST_ON_TINYISP: Q1.1 (B)
VCC: J3.1

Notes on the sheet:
VCC (output)
V_BAT (input)
RESET/ADC0
PWM/ADC3
SCK/SCL/ADC1
PWM/ADC2
MISO/PWM
AREF/MOSI/SDA/PWM
Gnd Reset Vcc SCL MISO MOSI
pin out to target AVR
PIN on chip 4 5 6 7 2 3 1 8
(not on header) VCC
GND
alternative packges to allow for smd or thro hole components

Board: 2 copper layers, 11 parts (0 on the bottom side), 2 nets, no tracks yet.

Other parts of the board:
U$3: OSHW_6X150_NOTEXT

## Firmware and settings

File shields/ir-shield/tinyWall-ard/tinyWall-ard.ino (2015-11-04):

// ATMEL ATTINY85 running @ 8MHz / ARDUINO **Zvi Schneider 12-May-2014**
//           		 +----\/---+
//  ADC0,  PB5, 	1|*           |8	VCC
//  ADC3,  PB3,	2|             |7	PB2,  ADC1
//  ADC2,  PB4,	3|             |6	PB1,
//  GND       	4|             |5	PB0,
//              		 +---------+
// http://telavivmakers.org/index.php/TinyWall
// https://github.com/telavivmakers/at-tami/tree/master/shields/ir-shield

#define my_milisec  76 // 76 interrupts equal 1 mili-sec (approximatly)
#define interval  100 //100 mili-sec interval between repetetive code transmitions
volatile long interrups_counter = 0;
byte virtual_wall = B10100010; // ROOMAs virtual wall code
int one_milisec = my_milisec;
int three_milisec = my_milisec * 3;

ISR (TIM0_COMPA_vect) { // interrupt service routine
  interrups_counter +=1;
}

void setup(){
  TCNT0 = 0; //initialize timer0 registers
  TCCR0A=0;
  TCCR0B=0;
  TCCR0A |=(1<<COM0A0); //Timer0 in toggle mode (Table 11-2)
  TCCR0A |=(1<<WGM01); //Timer0 in CTC mode (Table 11.5)
  TCCR0B |= (1 << CS00);// Prescaler (table 11.6, no prescaling)
  OCR0A=105-1; //CTC Compare value. with 8MHz clock and no prescaling this value will give interrupt every 13.125 micro-sec
  TIMSK |= 1<<OCIE0A; //enable timer0 OCR0A interrups
  SREG |= B10000000; //enable interrups
}

void loop(){
  while (interrups_counter < my_milisec*interval){ //wait interval miliseconds
  }
  interrups_counter = 0;
  xmitbyte(virtual_wall); //send one byte command to the ROOMBA
}

void xmitbyte(byte xmitdata){
  int i;
  int mark;
  int space;
  byte shift_one = B10000000;
  for (i = 0; i < 8; i++){
    if (xmitdata & shift_one){
      mark = three_milisec;
      space = one_milisec;
    }
    else {
      mark = one_milisec;
      space = three_milisec;
    }
    pinMode(PB0, OUTPUT); // mark, transmit IR pulses
    while (interrups_counter < mark){
    }
    interrups_counter = 0;
    pinMode(PB0, INPUT); // space, do not transmit IR pulses
    while (interrups_counter < space){
    }
    interrups_counter = 0;
    shift_one = shift_one >> 1;
  }
}

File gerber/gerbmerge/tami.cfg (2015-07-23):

# This configuration file demonstrates panelizing a single job.

##############################################################################
# In the [DEFAULT] section you can create global names to save typing the same
# directory name, for example, over and over.
##############################################################################
[DEFAULT]

# Change projdir to wherever your project files are, for example:
#
#   projdir = /home/stuff/projects/test
#
# or relative pathname from where you are running GerbMerge
#
#   projdir = testdata
#
# or if all files are in the current directory (as in this example):
#
#   projdir = .
projdir = .

# For convenience, this is the base name of the merged output files.
MergeOut = ATtami

#############################################################################
# The [Options] section defines settings that control how the input files are
# read and how the output files are generated.
#############################################################################
[Options]

################################################################
#
#               Settings that are very important
#
################################################################

# Option indicating name of file that maps Excellon tool codes to drill sizes.
# This is not necessary if the Excellon files have embedded tool sizes, or if a
# tool list is specified as part of the job description. The ToolList option
# here is the "last resort" for mapping tool codes to tool sizes. Most recent
# PCB programs embed drill size information right in the Excellon file, so this
# option should not be necessary and can be commented out.
#ToolList=proj1.drl

# Optional indication of the number of decimal places in input Excellon drill
# files. The default is 4 which works for recent versions of Eagle (since
# version 4.11r12), as well as Orcad and PCB. Older versions of Eagle use 3
# decimal places.
#ExcellonDecimals = 4

################################################################
#
#             Settings that are somewhat important
#
################################################################

# Which layers to draw cut lines on. Omit this option or set to 'None' for no
# cut lines. Cut lines are borders around each job that serve as guides for
# cutting the panel into individual jobs. Option 'CutLineWidth' sets the
# thickness of these cut lines.
#
# NOTE: Layer names are ALL LOWERCASE, even if you define them with uppercase
# letters below.
#CutLineLayers = *topsilkscreen,*bottomsilkscreen

# Which layers to draw crop marks on. Omit this option or set to 'None' for no
# crop marks. Crop marks are small L-shaped marks at the 4 corners of the final
# panel. These practically define the extents of the panel and are required by
# some board manufacturers. Crop marks are also required if you want to leave
# extra space around the final panel for tooling or handling.  Option
# 'CropMarkWidth' sets the thickness of these crop marks.
#
# NOTE: Layer names are ALL LOWERCASE, even if you define them with uppercase
# letters below.
#CropMarkLayers = *topsilkscreen,*bottomsilkscreen

# Set this option to the name of a file in which to write a Gerber fabrication
# drawing. Some board manufacturers require a fabrication drawing with panel
# dimensions and drill hit marks and drill legend. There's no harm in creating
# this file...you can ignore it if you don't need it.
#FabricationDrawingFile = %(mergeout)s.fab

# If FabricationDrawingFile is specified, you can provide an optional file name
# of a file containing arbitrary text to add to the fabrication drawing. This
# text can indicate manufacturing information, contact information, etc.
#FabricationDrawingText = %(projdir)s/fabdwg.txt

# Option to generate leading zeros in the output Excellon drill file, i.e., to
# NOT use leading-zero suppression. Some Gerber viewers cannot properly guess
# the Excellon file format when there are no leading zeros.  Set this option to
# 1 if your Gerber viewer is putting the drill holes in far off places that do
# not line up with component pads.
ExcellonLeadingZeros = 0

# Optional additional Gerber layer on which to draw a rectangle defining the
# extents of the entire panelized job. This will create a Gerber file (with
# name specified by this option) that simply contains a rectangle defining the
# outline of the final panel. This outline file is useful for circuit board
# milling to indicate a path for the router tool. There's no harm in creating
# this file...you can ignore it if you don't need it.
# OutlineLayerFile = %(mergeout)s.oln

# Optional additional Gerber layer on which to draw horizontal and vertical
# lines describing where to score (i.e., V-groove) the panel so that jobs
# can easily snap apart. These scoring lines will be drawn half-way between
# job borders.
ScoringFile = %(mergeout)s.sco
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

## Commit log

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2014-03-26 fixed stuff
    [Little-Wire.J+N.brd]
2014-04-08 fixed unrouted wires
    [Little-Wire.J+N.brd]
2014-05-08 changed name and updated to rev4
    [ATTAMI.sch, Little-Wire.J+N.sch]
2014-05-08 changed name and updated to rev04
    [ATTAMI.brd, Little-Wire.J+N.brd]
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2014-05-25 ver08
    [zvi] switched the LDO to MIC5225. also changed some capacitors.
    [ATTAMI.sch]
2014-05-25 ver 09
    [zvi] changed the schematics. MIC5205 is in together with its capacitor C3.
    The MIC5205 has two drawbacks:
    a. No guaranteed behavior for Vin < 5.5 V.
    b. No guaranteed behavior regarding reverse leakage.
    For applications with external supply greater than 5.5V there is no problem.
    We will have to test the reverse current issue when operating on USB 5V without external supply.
    We will have to test the dropout issue when operating on external supply lower than 5.5V.
    Anyhow we will be able to switch back to the MIC5225 without changing the PCB.
    [ATTAMI.sch]
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2014-06-04 ver 15b
    this could be printed....
    [ATTAMI.sch]
2014-06-04 ver 15c
    curved and fixed overlaps
    used DRU rules by OSHpark
    https://oshpark.com/guidelines
    [ATTAMI.brd]
2014-06-04 ver 15c
    no change
    [ATTAMI.brd]
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2014-06-12 ver 15b05
    now the polygon back silkscreen logo placed correctly, ready for panalizing(!)
    [ATTAMI.brd]
2014-06-12 15b06
    because of sobbing of online gerber checker
    https://www.freedfm.com/freedfm/0022376203858107/results/summary2.htm
    - enlarge fonts on silkscreen to min 5mil
    - removed some redundant polygons from bottom silk
    [ATTAMI.brd]
2014-06-16 Create ATTAMI-Shield-template.sch
    template for shields
    [ATTAMI-Shield-template.sch]
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2014-07-01 ver 17
    changed the USB connector to the "official" package
    MOLEX - 47346-0001 - MICRO USB TYPE B
    [ATTAMI.brd]
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2014-09-07 fix floating pin
    major error in voltage regualtor (U1). enable pin was not connected to
    VBAT in GKx batch :(.
    [ATTAMI.brd]
2014-09-07 expanded microusb pads
    also add OSHW logo
    and removed some drawings
    [ATTAMI.brd, ATTAMI.sch]
2014-09-07 silkscreen
    added slinkscreen to pads on the bottom
    remove tiny text from TAMI logo
    [ATTAMI.brd, ATTAMI.sch]
2014-09-08 seocnd batch to fab
    zv additions
    Added + and gnd marking near the coin-cell legs on bottom side of the
    PCB.
    Made some legend changing on the schematic.
    [ATTAMI.brd, ATTAMI.sch]
2014-10-02 ATTami version 0.00
    PB5 connected,
    Added version # on bnames layer
    disconnected usb shield from ground
    [ATTAMI-V0.00.brd, ATTAMI-V0.00.sch]
2014-10-28 same shield, with added mounting holes and better naming based on ver 0.00
    based on attami ver 0.00
    https://github.com/telavivmakers/at-tami/commit/00271a633f93de088d04ac549667f0e04d0c47cf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
    [ATTAMI-Shield-template.brd, ATTAMI-Shield-template.sch]
2014-10-28 servo shield - new
    also added names and labels on wires
    [ATTAMI-Shield-Servo.brd, ATTAMI-Shield-Servo.sch, ATTAMI-Shield-template.brd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]
2014-10-28 flipped servo power pins
    [ATTAMI-Shield-Servo.brd, ATTAMI-Shield-Servo.sch]
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2014-11-06 servo shield-no invert :(
    [ATTAMI-Shield-Servo.brd, ATTAMI-Shield-Servo.sch]
2014-11-24 midnight edition, 1x2 layout
    taking space of two ATTami (1800x900 mil) .
    leaving much place for silkscreen.
    power on the right, servos on the left
    no VCC pins on shield.
    bottom copper plate is no longer ground, its now V_BAT.
    [ATTAMI-Shield-Servo.brd, ATTAMI-Shield-Servo.sch]
2014-11-24 rough layout change
    switched position of servos for better layout
    [ATTAMI-Shield-Servo.brd]
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2014-11-25 WIP
    basing on http://elm-chan.org/works/sd8p/report.html
    | what cap and inductor to use?
    [ATTAMI-Shield-sounday.brd, ATTAMI-Shield-sounday.sch]
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2014-12-07 more work on generic shield
    also added an SVG with TAMI logo
    [ATTAMI-Shield-bread.brd, ATTAMI-Shield-bread.sch]
2014-12-11 a shield for the pololu stepper driver, basic idea of schema and layout
    the pinout of the eagle part is a total mess. need to make my own.
    notice the PB5/RESET pin trick
    [ATTAMI-Shield-stepperDriver.brd, ATTAMI-Shield-stepperDriver.sch]
2014-12-14 cont work on stepper shield
    mostly done, could work if we agree on V_BAT to 12V
    [ATTAMI-Shield-stepperDriver.brd, ATTAMI-Shield-stepperDriver.sch]
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2014-12-16 addded 4pin header for 12+ and I2C, not routed
    [ATTAMI-Shield-stepperDriver.brd, ATTAMI-Shield-stepperDriver.sch]
2014-12-16 fix switched pins in stepper lib
    1A <-> 1B
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2015-01-02 removed unuised ID pin from micro usb connector
    [ATTAMI-V0.00.brd, ATTAMI-V0.00.sch]
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2015-01-02 moved all parts to ATtami lib, trimmed it
    [ATTAMI-V0.00.brd, ATTAMI-V0.00.sch]
2015-01-03 updated layout
    including re-routing the EN-VIN connection on U1 and removing a few
    routes that allows for this design to work as a one layer board with a
    bit of work.
    [ATTAMI-V0.00.brd, ATTAMI-V0.00.sch]
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2015-01-08 changes in trace width (8mil) and fine tune the aliexpress microusb packge
    [ATTAMI-V0.00.brd, ATTAMI-V0.00.sch]
2015-01-08 new design with added AMS1117 voltage regulator
    with library reflecting the part
    [ATTAMI-V0.00.brd, ATTAMI-V0.00.sch]
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2015-01-10 didn't save last time :\
    [tutuShield.brd, tutuShield.sch]
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2015-01-11 updated shield tamplete to only use ATtami lib parts
    [ATTAMI-Shield-template.brd, ATTAMI-Shield-template.sch, ATTAMI-V0.00.sch]
2015-01-11 layout fixing and pdf
    [ATTAMI-V0.00.brd]
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2015-01-16 simplfy
    this is a driver design we need a barebone onn with High Speed
    Optoisolator SOIC 16 , 60V 4A.
    [ATTAMI-Shield-stepperDriver.brd, ATTAMI-Shield-stepperDriver.sch]
2015-01-16 added the pb5 as digitall/reset pin thing
    also text comments
    [tutuShield.brd, tutuShield.sch]
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2015-01-16 a version without the PB5 trick
    it might be a bit simpler but i think its worth it to stick to
    4af68e7c457e82ac5364ccc3b228164f2045e11b
    [tutuShield.brd, tutuShield.sch]
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2015-01-18 fix GND and VCC airwires
    [tutuShield.brd, tutuShield.sch]
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2015-01-19 Moved via because of DRC rules
    Moved via next to the main chip because of DRC rules and 'ratsnest'ed it
    [tutuShield.brd]
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2015-01-24 fixed vcc wire bugs
    [tutuShield.brd, tutuShield.sch]
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2015-01-28 fixed sizes of silkscreen fonts (was smaller then 32mil)
    [tutuShield.brd, tutuShield.sch]
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2015-03-09 fixed pwm misshap in tutu shield
    [tutuShield.brd, tutuShield.sch]
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2015-04-03 fixed tutushield, needs review
    [tutuShield.brd]
2015-04-03 fixed some github problems. added the jumper to allow for midi out. intgrated the 2nd voltage regulator to make it cheap again
    [ATTAMI-V0.00.brd]
2015-04-03 pushed the pb5 wire a bit to the cneter
    [ATTAMI-V0.00.brd]
2015-04-07 fixed attami.lbr , taken correct attami template from high-voltage-programmer schema
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2015-04-16 hopefully didnt bork everything with zvi pull req
    [ATTAMI-V0.00.brd, ATTAMI-V0.00.sch]
2015-04-16 fixed pesky unconnected wires in jumper,, and removed value from jumer
    [ATTAMI-V0.00.brd, ATTAMI-V0.00.sch]
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2015-07-22 10mil width traces and pushed the PB5 bottom trace up
    [ATTAMI-V0.00.brd]
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2015-07-23 new gerber sent to be approved by pcb house #1 for 2015
    [tami.cfg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]
2015-07-23 fixed some airwires in the board, and new panelize
    [ATTAMI-V0.00.brd]
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2015-07-23 a versin without the fancy LDO and SOT0232 for the X1117
    [ATTAMI-V0.00.brd, ATTAMI-V0.00.sch]
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2015-10-10 correction to bat/gnd marking on top silk, it was reversed
    [ATTAMI-V0.00.brd]
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2015-10-30 new gerber reflecting correct gnd/vcc silkscreen. also refernace to zofz 3d gerber viewr
    [ATTAMI-V0.00.GTL, ATTAMI-V0.00.GTO]
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2016-10-22 added udis brake, think thats the latest design 19.03.15
    [Udi's Bridge brake.sch]
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

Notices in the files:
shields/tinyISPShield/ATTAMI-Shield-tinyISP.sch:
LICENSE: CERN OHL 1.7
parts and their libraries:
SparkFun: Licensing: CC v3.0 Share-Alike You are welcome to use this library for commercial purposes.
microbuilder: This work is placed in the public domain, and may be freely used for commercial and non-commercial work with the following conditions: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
